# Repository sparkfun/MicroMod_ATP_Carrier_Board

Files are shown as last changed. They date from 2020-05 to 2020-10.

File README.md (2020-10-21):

SparkFun MicroMod ATP Carrier Board
========================================

SparkFun MicroMod ATP Carrier Board (DEV-16885) (https://www.sparkfun.com/products/16885)

[*SparkFun MicroMod ATP Carrier Board (DEV-16885)*](https://www.sparkfun.com/products/16885)

<Basic description of the part.>

Repository Contents
-------------------

* **/Documentation** - Data sheets, additional product information
* **/Firmware** - Example code 
* **/Hardware** - Eagle design files (.brd, .sch)
* **/Production** - Production panel files (.brd)

Documentation
--------------
* **[Hookup Guide](https://learn.sparkfun.com/tutorials/micromod-all-the-pins-atp-carrier-board)** - Basic hookup guide

Product Versions
----------------
* [DEV-16885](https://www.sparkfun.com/products/16885)

Version History
---------------
* [v1.1](https://github.com/sparkfun/MicroMod_ATP_Carrier_Board/tree/v1.1) - Initial Release 

License Information
-------------------

This product is _**open source**_! 

Please review the LICENSE.md file for license information. 

If you have any questions or concerns on licensing, please contact technical support on our [SparkFun forums](https://forum.sparkfun.com/viewforum.php?f=152).

Distributed as-is; no warranty is given.

- Your friends at SparkFun.

_<COLLABORATION CREDIT>_

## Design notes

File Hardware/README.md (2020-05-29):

SparkFun <PRODUCT NAME> Design Files
=====================================

The .sch and .brd files hare are Eagle CAD schematic and PCB design files from SparkFun Electronics.
A freeware version of Eagle can be found [here](http://www.cadsoftusa.com/download-eagle/freeware/).

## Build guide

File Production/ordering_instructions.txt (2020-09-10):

panel size, 195x120mm
PCB thickness, 1.6mm
number of layers, 2
soldermask color, Red
silkscreen color, White
oz copper, 1oz
finish, HASL lead free
stencils, top
pcs per panel, 4
min trace width, 0.1524mm / 0.0060in
min drill size, 0.3048mm / 0.0120in

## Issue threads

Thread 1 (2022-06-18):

I2S_WS or I2S_FS on MicroMod ATP Carrier Board

dboddie, 2022-06-18:
### Subject of the issue
I2S_WS label in the schematic is not present on the board. Either the marking on the board is incorrect or the schematic is wrong.

### Your workbench
* What version of hardware or breakout board are you using?
MicroMod ATP Carrier Board

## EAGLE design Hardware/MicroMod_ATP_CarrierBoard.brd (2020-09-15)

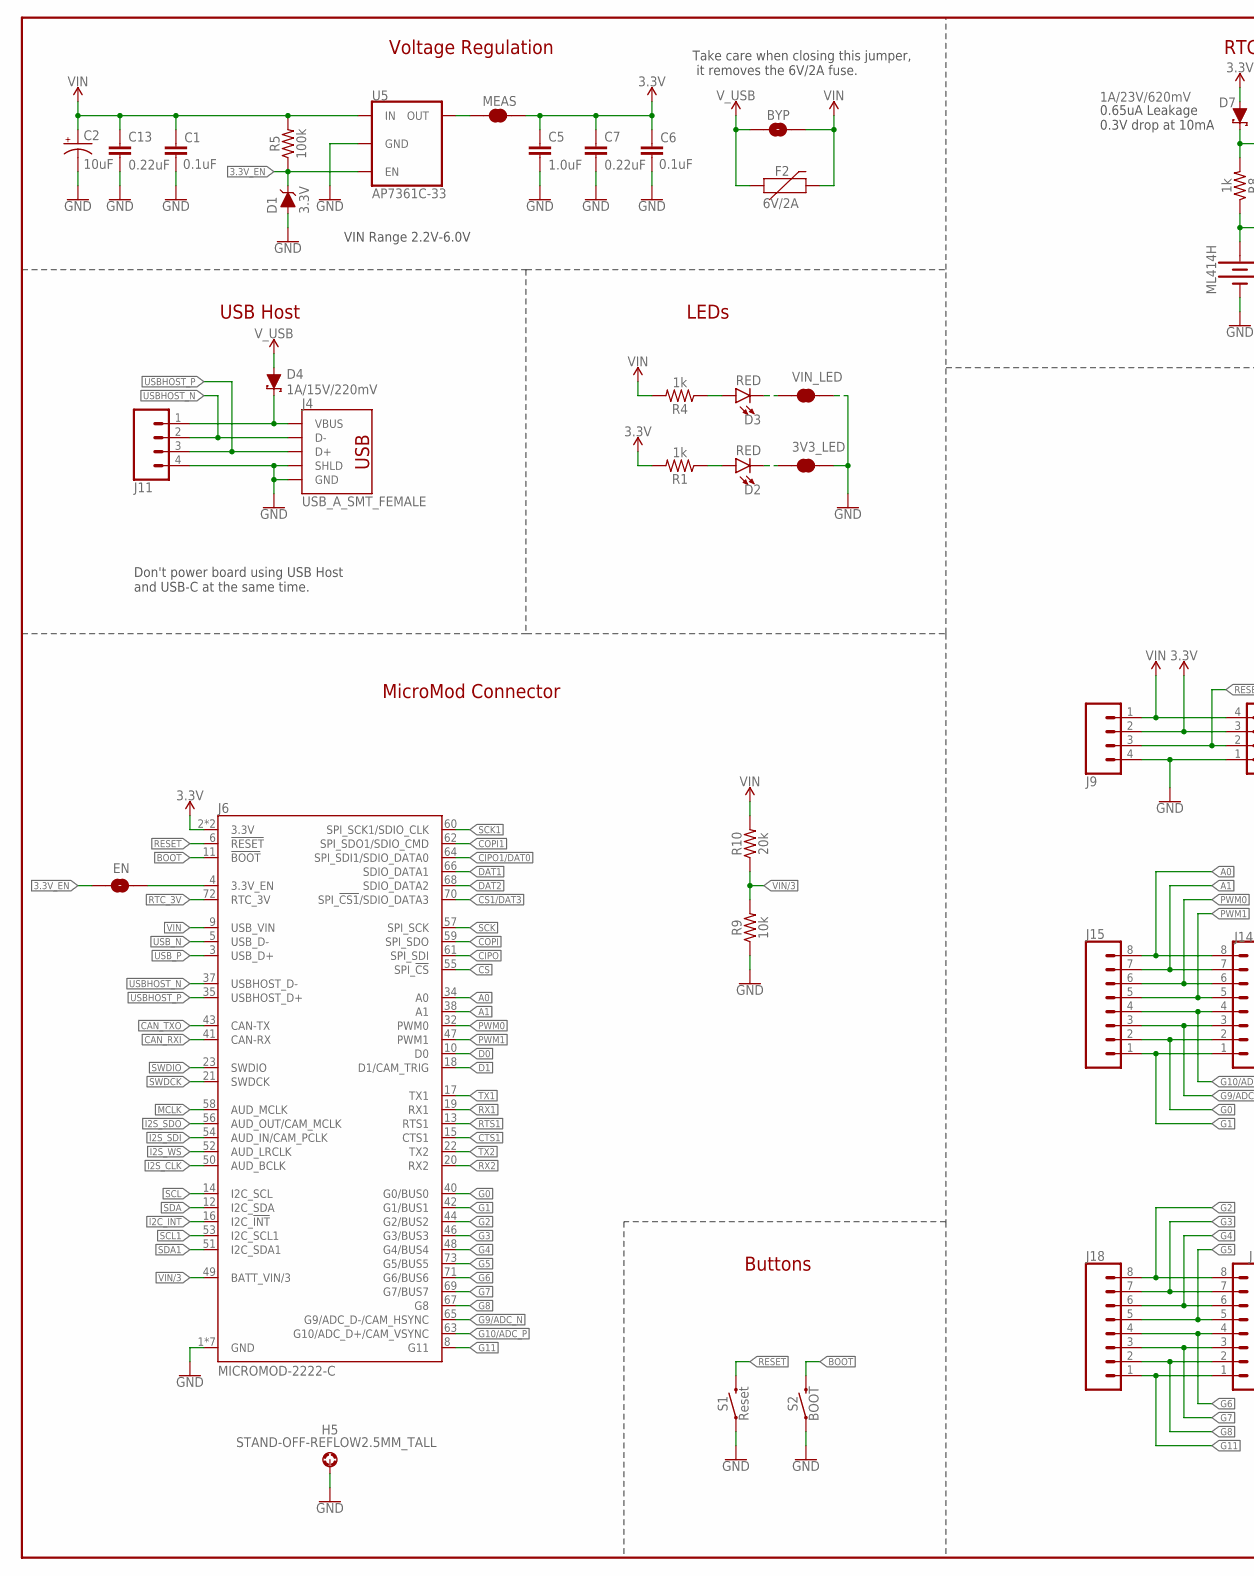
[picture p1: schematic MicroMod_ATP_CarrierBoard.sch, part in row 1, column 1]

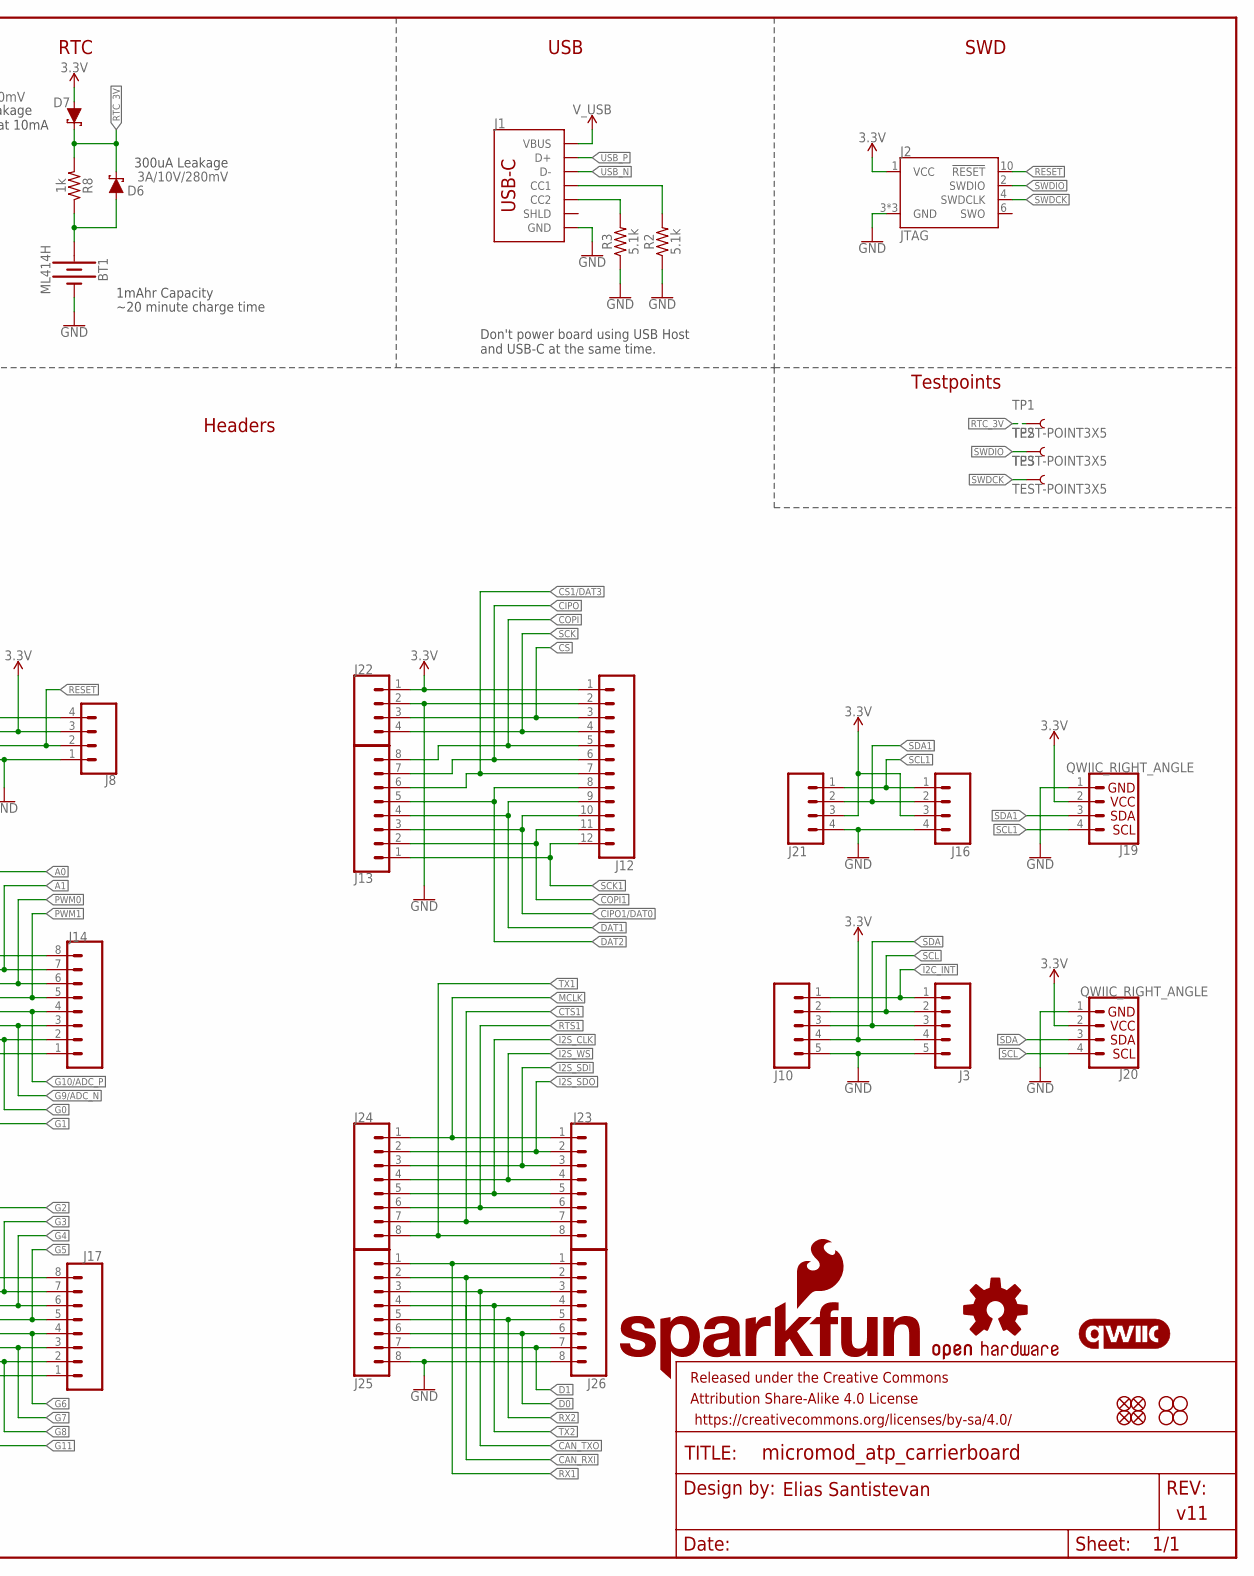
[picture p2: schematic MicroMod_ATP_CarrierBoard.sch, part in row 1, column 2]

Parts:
3V3_LED: JUMPER-SMT_2_NC_TRACE_SILK; SMT-JUMPER_2_NC_TRACE_SILK
BT1: ML414H; ML414H_IV01E
BYP: JUMPER-SMT_2_NO_SILK; SMT-JUMPER_2_NO_SILK
C1, C6: 0.1uF; 0603
C2: 10uF; EIA3216
C5: 1.0uF; 0603
C7, C13: 0.22uF; 0603
D1: 3.3V; SOD-323
D2, D3: RED; LED-0603
D4: 1A/15V/220mV; DO-214BA
D6: 3A/10V/280mV; SOD-323
D7: 1A/23V/620mV; SOD-323
EN: JUMPER-SMT_2_NO_SILK; SMT-JUMPER_2_NO_SILK
F2: 6V/2A; 1210
FD1, FD2, FD3, FD4: FIDUCIALUFIDUCIAL; FIDUCIAL-MICRO
FRAME1: FRAME-LEDGER; CREATIVE_COMMONS
H1, H2, H3, H4: STAND-OFF
H5: STAND-OFF-REFLOW2.5MM_TALL; STAND-OFF-REFLOW-M2.5
J1: USB_C_2-LAYER_PADS; USB-C-16P-2LAYER-PADS
J2: JTAG; 2X5-PTH-1.27MM
J3: CONN_05NO_SILK; 1X05_NO_SILK
J4: USB_A_SMT_FEMALE; USB-A-S-SILK-FEMALE
J6: MICROMOD-2222-C; M.2-CONNECTOR-E
J8, J21: 1X04_SMD_STRAIGHT_COMBO; 1X04_SMD_VERTICAL_COMBO
J9: CONN_041X04_NO_SILK; 1X04_NO_SILK
J10: CONN_05VERT_FEMALE_HEADER; 1X05_SMD_VERTICAL_COMBO
J11, J16, J22: CONN_041X04_NO_SILK_NO_POP; 1X04_NO_SILK
J12: CONN_12SMD_COMBINED; 1X12_SMD_COMBINED
J13: CONN_08NO_SILK_DNP; 1X08_NO_SILK
J14, J17, J24, J25: CONN_08SMD-COMBO-FEMALE; 1X08_SMD_COMBINED
J15, J18, J23, J26: CONN_08NO_SILK_FEMALE_PTH; 1X08_NO_SILK
J19, J20: QWIIC_RIGHT_ANGLE; JST04_1MM_RA
LOGO1: SFE_LOGO_NAME_FLAME.1_INCH; SFE_LOGO_NAME_FLAME_.1
LOGO2: QWIIC_LOGO_5MM; QWIIC_5MM
LOGO3: OSHW-LOGOMINI; OSHW-LOGO-MINI
MEAS: JUMPER-COMBO_2_NC_TRACE; COMBO-JUMPER_2_NC_TRACE
R1, R4, R8: 1k; 0603
R2, R3: 5.1k; 0603
R5: 100k; 0603
R9: 10k; 0603
R10: 20k; 0603
S1: Reset; TACTILE_SWITCH_SMD_5.2MM
S2: BOOT; TACTILE_SWITCH_SMD_5.2MM
TP1, TP2, TP3: TEST-POINT3X5; PAD.03X.05
U5: AP7361C-33; UDFN-8
VIN_LED: JUMPER-SMT_2_NC_TRACE_SILK; SMT-JUMPER_2_NC_TRACE_SILK

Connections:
3.3V: C5.1, C6.1, C7.1, D7.A, J2.1 (VCC), J3.4, J6.2 (3.3V), J6.74 (3.3V), J8.3, J9.2, J10.4, J12.1, J16.3, J19.2, J20.2, J21.3, J22.1, MEAS.2, MEAS.4 (2), R1.2
3.3V_EN: D1.C, EN.1, R5.1, U5.5 (EN)
!BOOT!: J6.11 (!BOOT!), S2.3 (2), S2.4 (2)
!CS1!/DAT3: J6.70 (SPI_!CS1!/SDIO_DATA3), J12.7, J13.6
!CS!: J6.55 (SPI_!CS!), J12.3, J22.3
!RESET: J2.10 (!RESET), J6.6 (!RESET!), J8.2, J9.3, S1.3 (2), S1.4 (2)
A0: J6.34 (A0), J14.8, J15.8
A1: J6.38 (A1), J14.7, J15.7
CAN_RXI: J6.41 (CAN-RX), J25.2, J26.2
CAN_TXO: J6.43 (CAN-TX), J25.3, J26.3
CIPO: J6.61 (SPI_SDI), J12.6, J13.7
CIPO1/DAT0: J6.64 (SPI_SDI1/SDIO_DATA0), J12.10, J13.3
COPI: J6.59 (SPI_SDO), J12.5, J13.8
COPI1: J6.62 (SPI_SDO1/SDIO_CMD), J12.11, J13.2
CTS1: J6.15 (CTS1), J23.7, J24.7
D0: J6.10 (D0), J25.6, J26.6
D1: J6.18 (D1/CAM_TRIG), J25.7, J26.7
DAT1: J6.66 (SDIO_DATA1), J12.9, J13.4
DAT2: J6.68 (SDIO_DATA2), J12.8, J13.5
G0: J6.40 (G0/BUS0), J14.2, J15.2
G1: J6.42 (G1/BUS1), J14.1, J15.1
G2: J6.44 (G2/BUS2), J17.8, J18.8
G3: J6.46 (G3/BUS3), J17.7, J18.7
G4: J6.48 (G4/BUS4), J17.6, J18.6
G5: J6.73 (G5/BUS5), J17.5, J18.5
G6: J6.71 (G6/BUS6), J17.4, J18.4
G7: J6.69 (G7/BUS7), J17.3, J18.3
G8: J6.67 (G8), J17.2, J18.2
G9/ADC_N: J6.65 (G9/ADC_D-/CAM_HSYNC), J14.3, J15.3
G10/ADC_P: J6.63 (G10/ADC_D+/CAM_VSYNC), J14.4, J15.4
G11: J6.8 (G11), J17.1, J18.1
GND: 3V3_LED.2, BT1.-, C1.2, C2.-, C5.2, C6.2, C7.2, C13.2, D1.A, H5.1, J1.GND, J1.GND2 (GND), J2.3 (GND), J2.5 (GND), J2.9 (GND), J3.5, J4.GND, J4.SHLD1 (SHLD), J4.SHLD2 (SHLD), J6.1 (GND), J6.7 (GND), J6.33 (GND), J6.36 (GND), J6.39 (GND), J6.45 (GND), J6.75 (GND), J8.1, J9.4, J10.5, J11.4, J12.2, J16.4, J19.1, J20.1, J21.4, J22.2, J25.8, J26.8, R2.1, R3.1, R9.1, S1.1, S1.2 (1), S2.1, S2.2 (1), U5.4 (GND), U5.EP (GND), VIN_LED.2
I2C_!INT: J3.1, J6.16 (I2C_!INT!), J10.1
I2S_CLK: J6.50 (AUD_BCLK), J23.5, J24.5
I2S_SDI: J6.54 (AUD_IN/CAM_PCLK), J23.3, J24.3
I2S_SDO: J6.56 (AUD_OUT/CAM_MCLK), J23.2, J24.2
I2S_WS: J6.52 (AUD_LRCLK), J23.4, J24.4
MCLK: J6.58 (AUD_MCLK), J23.1, J24.1
unnamed: D2.A, R1.1
unnamed: D3.A, R4.1
unnamed: 3V3_LED.1, D2.C
unnamed: D3.C, VIN_LED.1
unnamed: EN.2, J6.4 (3.3V_EN)
unnamed: D4.C, J4.VBUS, J11.1
unnamed: J1.A5 (CC1), R2.2
unnamed: J1.B5 (CC2), R3.2
unnamed: BT1.+, D6.A, R8.1
OUT_MEAS: MEAS.1, MEAS.3 (1), U5.1 (OUT)
PWM0: J6.32 (PWM0), J14.6, J15.6
PWM1: J6.47 (PWM1), J14.5, J15.5
RTC_3V: D6.C, D7.C, J6.72 (RTC_3V), R8.2, TP1.P$1
RTS1: J6.13 (RTS1), J23.6, J24.6
RX1: J6.19 (RX1), J25.1, J26.1
RX2: J6.20 (RX2), J25.5, J26.5
SCK: J6.57 (SPI_SCK), J12.4, J22.4
SCK1: J6.60 (SPI_SCK1/SDIO_CLK), J12.12, J13.1
SCL: J3.2, J6.14 (I2C_SCL), J10.2, J20.4
SCL1: J6.53 (I2C_SCL1), J16.1, J19.4, J21.1
SDA: J3.3, J6.12 (I2C_SDA), J10.3, J20.3
SDA1: J6.51 (I2C_SDA1), J16.2, J19.3, J21.2
SWDCK: J2.4 (SWDCLK), J6.21 (SWDCK), TP3.P$1
SWDIO: J2.2 (SWDIO), J6.23 (SWDIO), TP2.P$1
TX1: J6.17 (TX1), J23.8, J24.8
TX2: J6.22 (TX2), J25.4, J26.4
USBHOST_N: J4.D-, J6.37 (USBHOST_D-), J11.2
USBHOST_P: J4.D+, J6.35 (USBHOST_D+), J11.3
USB_N: J1.A7 (D-), J1.B7 (D-), J6.5 (USB_D-)
USB_P: J1.A6 (D+), J1.B6 (D+), J6.3 (USB_D+)
VIN: BYP.2, C1.1, C2.+, C13.1, F2.2, J6.9 (USB_VIN), J8.4, J9.1, R4.2, R5.2, R10.2, U5.8 (IN)
VIN/3: J6.49 (BATT_VIN/3), R9.2, R10.1
V_USB: BYP.1, D4.A, F2.1, J1.VBUS1 (VBUS), J1.VBUS2 (VBUS)

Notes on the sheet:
300uA Leakage
0.65uA Leakage 0.3V drop at 10mA
~20 minute charge time
1mAhr Capacity
Take care when closing this jumper, it removes the 6V/2A fuse.
SWD
USB
Headers
RTC
Voltage Regulation
MicroMod Connector
Elias Santistevan
LEDs
USB Host
Buttons
v11
VIN Range 2.2V-6.0V
Don't power board using USB Host and USB-C at the same time.
Testpoints

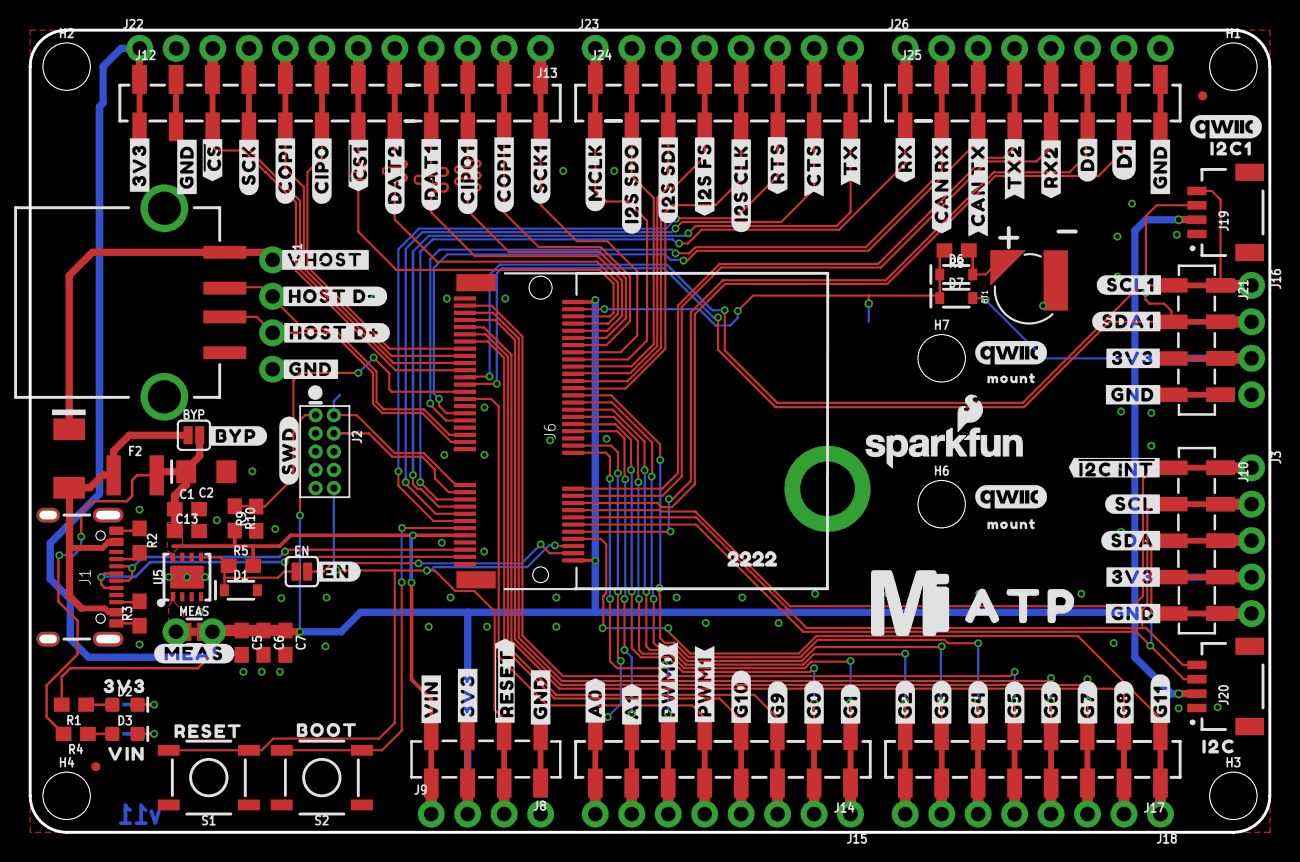
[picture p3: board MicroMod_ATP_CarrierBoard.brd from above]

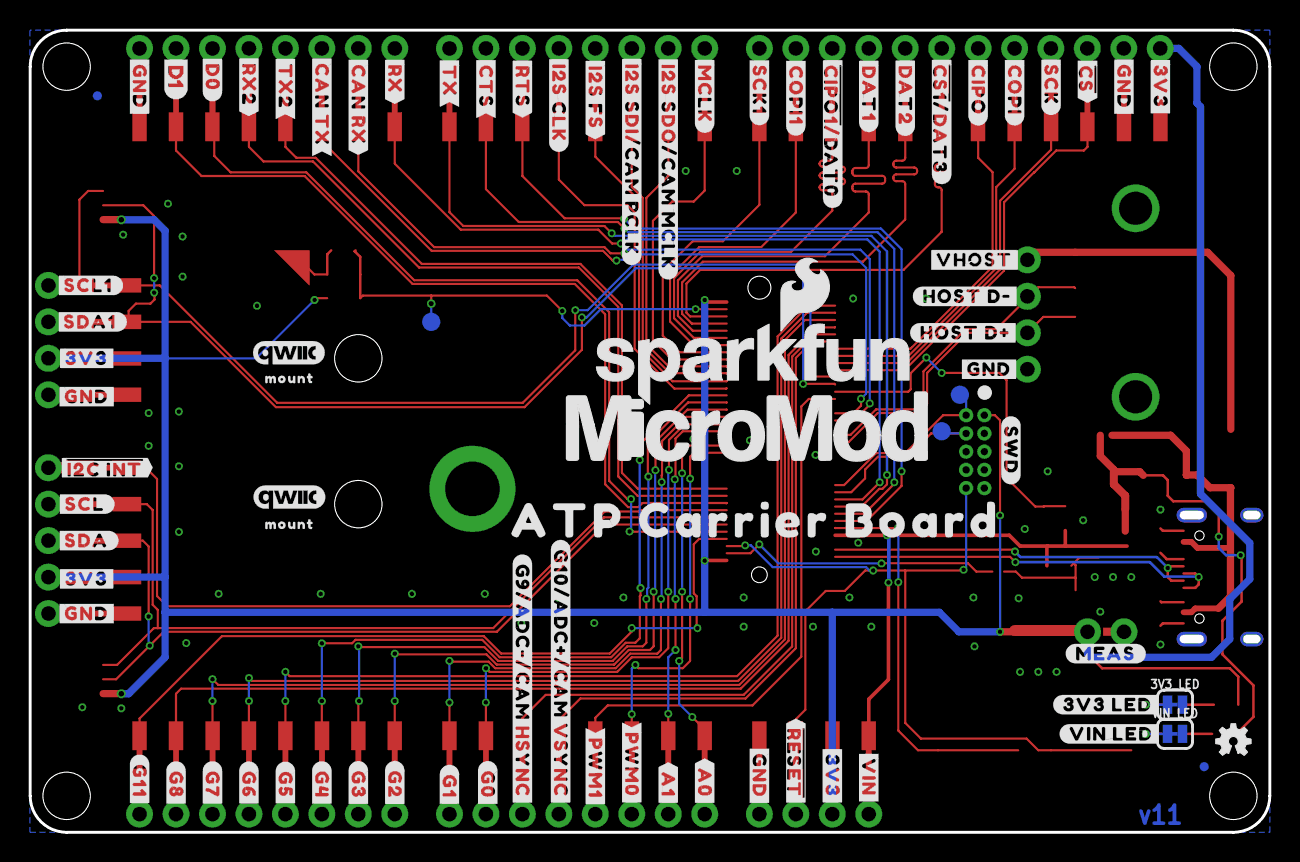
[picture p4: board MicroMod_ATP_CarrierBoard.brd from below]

Board: 2 copper layers, 86.4 x 55.9 mm, 222 parts (80 on the bottom side), 71 nets.

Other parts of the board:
H6, H7: STAND-OFF
LOGO4: SFE_LOGO_NAME_FLAME.2_INCH; SFE_LOGO_NAME_FLAME_.2
LOGO5, LOGO6, LOGO7, LOGO8: QWIIC_LOGO_3MM; QWIIC_5MM
U$1, U$123: #A0#10
U$2, U$124: #A1#10
U$3, U$27, U$46, U$47, U$58, U$89, U$100, U$101, U$102, U$103, U$104, U$105: #GND#0
U$4, U$120: #G0#2
U$5: #RESET10
U$6, U$98: #D0#0
U$7, U$119: #G1#2
U$8, U$118: #G2#2
U$9, U$117: #G3#3
U$10, U$116: #G4#4
U$11, U$115: #G5#5
U$12, U$114: #G6#6
U$13, U$113: #G7#7
U$14, U$112: #G8#8
U$15: #G9#9
U$16: #G10#10
U$17, U$111: #G11#10
U$18, U$121: #PWM0#10
U$19, U$122: #PWM1#10
U$20: ##CS1##5178039
U$21, U$110: ##I2C_INT##10
U$22: #CAN_RX#9
U$23, U$97: #CAN_TX#10
U$24: #CIPO#3
U$25: #COPI#2
U$26: #CTS#6
U$28: #SCK#2
U$29: #I2S_FS#5
U$30: #I2S_SDI#5
U$31: #I2S_SDO#5
U$32: #MCLK#4
U$33: #RTS#5
U$34: #RX#8
U$35: #TX#7
U$36: #DAT1#5178039
U$37, U$125: ##RESET##7
U$38, U$60, U$61, U$70, U$88, U$106, U$107, U$126: #3V3#1
U$39: #BYP#8
U$40, U$128: #HOST_D##9
U$41, U$129: #HOST_D##10
U$42, U$132: #MEAS#10
U$43: BOOT10
U$44, U$108: #SDA#4
U$45, U$127: #VIN#6
U$48: #EN#0
U$49, U$109: #SCL#5
U$50, U$146: #VHOST#0
U$51, U$131: #SWD#10
U$52: #I2S_CLK#5
U$53: #DAT2#5178039
U$54: #CIPO1#5178039
U$55: 22229
U$56: ##CIPO1##DAT0#5178038
U$57, U$75: #COPI1#2
U$59: ##CS##0
U$62: ATP0
U$63, U$76: #RX2#3
U$64, U$80: #TX2#2
U$65, U$78: #SCL1#3
U$66, U$79: #SDA1#3
U$67, U$77: #SCK1#2
U$68: VIN3
U$69: 3V34
U$71: I2C4
U$72: I2C14
U$73: ATP_CARRIER_BOARD1
U$81: ##CS##5178037
U$82: #DAT2#5
U$83: #DAT1#5
U$84: ##CS1##DAT3#5178037
U$85: #COPI#4
U$86: #SCK#4
U$87: #MCLK#6
U$90: #I2S_FS#7
U$91: #I2S_CLK#7
U$92: #RTS#7
U$93: #CTS#8
U$94: #TX#9
U$95: #RX#10
U$96: #CAN_RX#10
U$99, U$145: D10
U$133: #VIN_LED#10
U$134: #3V3_LED#10
U$135: #G9#ADC##CAM_HSYNC#9
U$136: #G10#ADC##CAM_VSYNC#10
U$137: #I2S_SDI#CAM_PCLK#7
U$138: #I2S_SDO#CAM_MCLK#7
U$139, U$141, U$142, U$143: MOUNT10
U$140: MICROMOD_MI_LOGO_1
U$144: MICROMOD_LOGO_1
U$147: #CIPO#5178038

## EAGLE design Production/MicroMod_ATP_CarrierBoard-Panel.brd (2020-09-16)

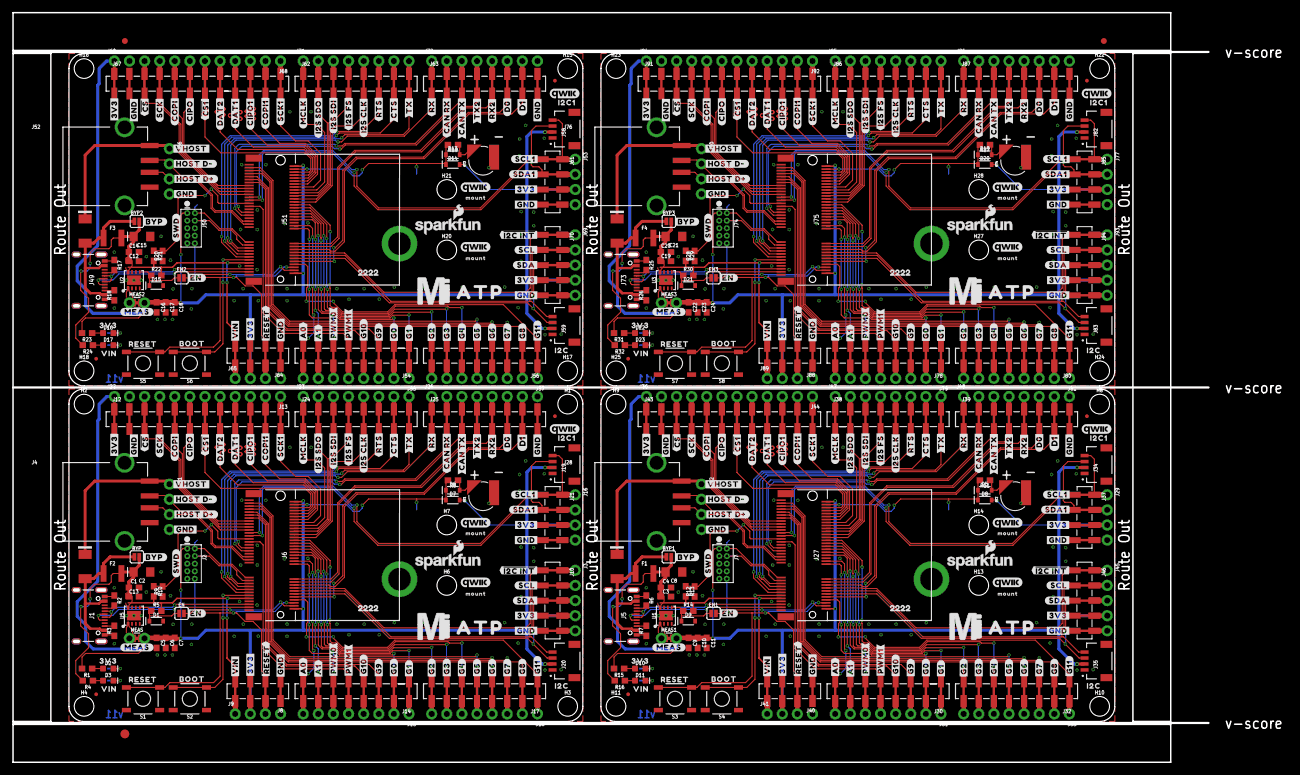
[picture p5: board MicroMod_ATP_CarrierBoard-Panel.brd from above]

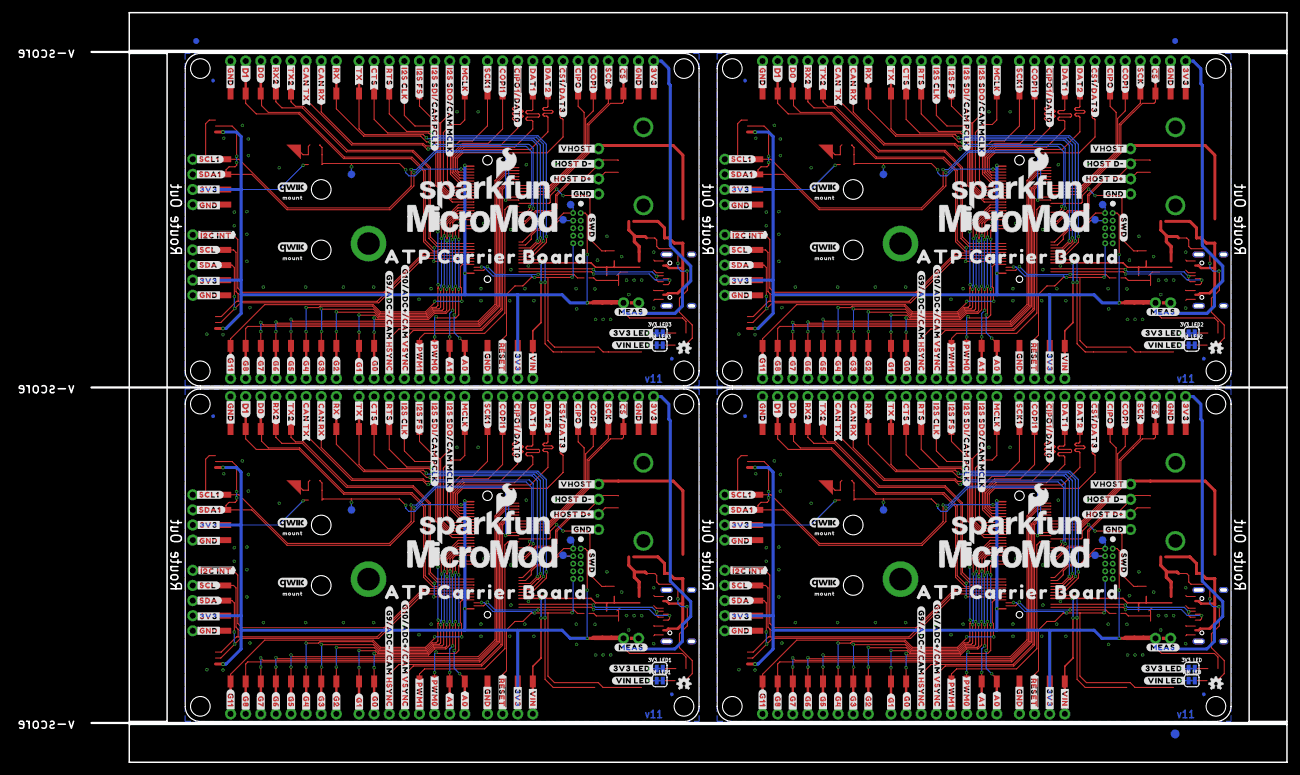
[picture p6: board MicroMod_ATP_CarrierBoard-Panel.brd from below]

Board: 2 copper layers, 200.9 x 126.0 mm, 890 parts (323 on the bottom side), 284 nets.

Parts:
3V3_LED, 3V3_LED1, 3V3_LED2, 3V3_LED3: JUMPER-SMT_2_NC_TRACE_SILK; SMT-JUMPER_2_NC_TRACE_SILK
BT1, BT2, BT3, BT4: ML414H; ML414H_IV01E
BYP, BYP1, BYP2, BYP3: JUMPER-SMT_2_NO_SILK; SMT-JUMPER_2_NO_SILK
C1, C4, C6, C10, C14, C17, C20, C23: 0.1uF; 0603
C2, C8, C15, C21: 10uF; EIA3216
C3, C7, C11, C12, C13, C18, C19, C24: 0.22uF; 0603
C5, C9, C16, C22: 1.0uF; 0603
D1, D9, D15, D21: 3.3V; SOD-323
D2, D3, D10, D11, D16, D17, D22, D23: RED; LED-0603
D4, D12, D18, D24: 1A/15V/220mV; DO-214BA
D5, D6, D13, D19: 3A/10V/280mV; SOD-323
D7, D8, D14, D20: 1A/23V/620mV; SOD-323
E$1, E$2, E$3, E$4: FIDUCIAL-1X2
E$5, E$6: FIDUCIAL-1.5X3
EN, EN1, EN2, EN3: JUMPER-SMT_2_NO_SILK; SMT-JUMPER_2_NO_SILK
F1, F2, F3, F4: 6V/2A; 1210
FD1, FD2, FD3, FD4, FD5, FD6, FD7, FD8, FD9, FD10, FD11, FD12, FD13, FD14, FD15, FD16: FIDUCIALUFIDUCIAL; FIDUCIAL-MICRO
H1, H2, H3, H4, H6, H7, H8, H9, H10, H11, H13, H14, H15, H16, H17, H18, H20, H21, H22, H23, H24, H25, H27, H28: STAND-OFF
H5, H12, H19, H26: STAND-OFF-REFLOW2.5MM_TALL; STAND-OFF-REFLOW-M2.5
J1, J5, J49, J73: USB-C-16P-2LAYER-PADS
J2, J7, J50, J74: JTAG; 2X5-PTH-1.27MM
J3, J45, J69, J93: 1X05_NO_SILK
J4, J28, J52, J76: USB_A_SMT_FEMALE; USB-A-S-SILK-FEMALE
J6, J27, J51, J75: MICROMOD-2222-C; M.2-CONNECTOR-E
J8, J21, J37, J40, J61, J64, J85, J88: 1X04_SMD_STRAIGHT_COMBO; 1X04_SMD_VERTICAL_COMBO
J9, J11, J16, J22, J29, J36, J41, J42, J53, J60, J65, J66, J77, J84, J89, J90: 1X04_NO_SILK
J10, J46, J70, J94: 1X05_SMD_VERTICAL_COMBO
J12, J43, J67, J91: 1X12_SMD_COMBINED
J13, J15, J18, J23, J26, J31, J33, J44, J47, J48, J55, J57, J68, J71, J72, J79, J81, J92, J95, J96: 1X08_NO_SILK
J14, J17, J24, J25, J30, J32, J38, J39, J54, J56, J62, J63, J78, J80, J86, J87: 1X08_SMD_COMBINED
J19, J20, J34, J35, J58, J59, J82, J83: QWIIC_RIGHT_ANGLE; JST04_1MM_RA
LOGO1, LOGO11, LOGO19, LOGO27: SFE_LOGO_NAME_FLAME.1_INCH; SFE_LOGO_NAME_FLAME_.1
LOGO2, LOGO15, LOGO23, LOGO31: QWIIC_LOGO_5MM; QWIIC_5MM
LOGO3, LOGO9, LOGO17, LOGO25: OSHW-LOGOMINI; OSHW-LOGO-MINI
LOGO4, LOGO10, LOGO18, LOGO26: SFE_LOGO_NAME_FLAME.2_INCH; SFE_LOGO_NAME_FLAME_.2
LOGO5, LOGO6, LOGO7, LOGO8, LOGO12, LOGO13, LOGO14, LOGO16, LOGO20, LOGO21, LOGO22, LOGO24, LOGO28, LOGO29, LOGO30, LOGO32: QWIIC_LOGO_3MM; QWIIC_5MM
MEAS, MEAS1, MEAS2, MEAS3: COMBO-JUMPER_2_NC_TRACE
R1, R4, R8, R11, R15, R16, R19, R23, R24, R27, R31, R32: 1k; 0603
R2, R3, R6, R7, R17, R18, R25, R26: 5.1k; 0603
R5, R14, R22, R30: 100k; 0603
R9, R12, R20, R28: 10k; 0603
R10, R13, R21, R29: 20k; 0603
S1, S3, S5, S7: Reset; TACTILE_SWITCH_SMD_5.2MM
S2, S4, S6, S8: BOOT; TACTILE_SWITCH_SMD_5.2MM
TP1, TP2, TP3, TP4, TP5, TP6, TP7, TP8, TP9, TP10, TP11, TP12: TEST-POINT3X5; PAD.03X.05
U1, U2, U3, U5: AP7361C-33; UDFN-8
U$1, U$123, U$169, U$251, U$314, U$396, U$459, U$541: #A0#10
U$2, U$124, U$170, U$252, U$315, U$397, U$460, U$542: #A1#10
U$3, U$27, U$46, U$47, U$58, U$89, U$100, U$101, U$102, U$103, U$104, U$105, U$160, U$166, U$167, U$228, U$229, U$230, U$231, U$232, U$233, U$268, U$269, U$270, U$305, U$311, U$312, U$373, U$374, U$375, U$376, U$377, U$378, U$413, U$414, U$415, U$450, U$456, U$457, U$518, U$519, U$520, U$521, U$522, U$523, U$558, U$559, U$560: #GND#0
U$4, U$120, U$172, U$248, U$317, U$393, U$462, U$538: #G0#2
U$5, U$163, U$308, U$453: #RESET10
U$6, U$98, U$171, U$227, U$316, U$372, U$461, U$517: #D0#0
U$7, U$119, U$173, U$247, U$318, U$392, U$463, U$537: #G1#2
U$8, U$118, U$174, U$246, U$319, U$391, U$464, U$536: #G2#2
U$9, U$117, U$175, U$245, U$320, U$390, U$465, U$535: #G3#3
U$10, U$116, U$176, U$244, U$321, U$389, U$466, U$534: #G4#4
U$11, U$115, U$177, U$243, U$322, U$388, U$467, U$533: #G5#5
U$12, U$114, U$178, U$242, U$323, U$387, U$468, U$532: #G6#6
U$13, U$113, U$179, U$241, U$324, U$386, U$469, U$531: #G7#7
U$14, U$112, U$180, U$240, U$325, U$385, U$470, U$530: #G8#8
U$15, U$181, U$326, U$471: #G9#9
U$16, U$182, U$327, U$472: #G10#10
U$17, U$111, U$183, U$239, U$328, U$384, U$473, U$529: #G11#10
U$18, U$121, U$184, U$249, U$329, U$394, U$474, U$539: #PWM0#10
U$19, U$122, U$185, U$250, U$330, U$395, U$475, U$540: #PWM1#10
U$20, U$286, U$431, U$576: ##CS1##5178039
U$21, U$110, U$238, U$271, U$383, U$416, U$528, U$561: ##I2C_INT##10
U$22, U$130, U$292, U$437: #CAN_RX#9
U$23, U$97, U$148, U$226, U$293, U$371, U$438, U$516: #CAN_TX#10
U$24, U$149, U$294, U$439: #CIPO#3
U$25, U$150, U$295, U$440: #COPI#2
U$26, U$151, U$296, U$441: #CTS#6
U$28, U$267, U$412, U$557: #SCK#2
U$29, U$152, U$297, U$442: #I2S_FS#5
U$30, U$153, U$298, U$443: #I2S_SDI#5
U$31, U$154, U$299, U$444: #I2S_SDO#5
U$32, U$155, U$300, U$445: #MCLK#4
U$33, U$156, U$301, U$446: #RTS#5
U$34, U$157, U$302, U$447: #RX#8
U$35, U$158, U$303, U$448: #TX#7
U$36, U$287, U$432, U$577: #DAT1#5178039
U$37, U$125, U$206, U$253, U$351, U$398, U$496, U$543: ##RESET##7
U$38, U$60, U$61, U$70, U$88, U$106, U$107, U$126, U$197, U$198, U$199, U$200, U$234, U$235, U$254, U$266, U$342, U$343, U$344, U$345, U$379, U$380, U$399, U$411, U$487, U$488, U$489, U$490, U$524, U$525, U$544, U$556: #3V3#1
U$39, U$159, U$304, U$449: #BYP#8
U$40, U$128, U$161, U$256, U$306, U$401, U$451, U$546: #HOST_D##9
U$41, U$129, U$162, U$257, U$307, U$402, U$452, U$547: #HOST_D##10
U$42, U$132, U$186, U$259, U$331, U$404, U$476, U$549: #MEAS#10
U$43, U$164, U$309, U$454: BOOT10
U$44, U$108, U$187, U$236, U$332, U$381, U$477, U$526: #SDA#4
U$45, U$127, U$165, U$255, U$310, U$400, U$455, U$545: #VIN#6
U$48, U$280, U$425, U$570: #EN#0
U$49, U$109, U$168, U$237, U$313, U$382, U$458, U$527: #SCL#5
U$50, U$146, U$281, U$282, U$426, U$427, U$571, U$572: #VHOST#0
U$51, U$131, U$188, U$258, U$333, U$403, U$478, U$548: #SWD#10
U$52, U$189, U$334, U$479: #I2S_CLK#5
U$53, U$288, U$433, U$578: #DAT2#5178039
U$54, U$289, U$434, U$579: #CIPO1#5178039
U$55, U$74, U$291, U$436: 22229
U$56, U$290, U$435, U$580: ##CIPO1##DAT0#5178038
U$57, U$75, U$205, U$208, U$350, U$353, U$495, U$498: #COPI1#2
U$59, U$207, U$352, U$497: ##CS##0
U$62, U$201, U$346, U$491: ATP0
U$63, U$76, U$190, U$209, U$335, U$354, U$480, U$499: #RX2#3
U$64, U$80, U$191, U$213, U$336, U$358, U$481, U$503: #TX2#2
U$65, U$78, U$192, U$211, U$337, U$356, U$482, U$501: #SCL1#3
U$66, U$79, U$193, U$212, U$338, U$357, U$483, U$502: #SDA1#3
U$67, U$77, U$194, U$210, U$339, U$355, U$484, U$500: #SCK1#2
U$68, U$195, U$340, U$485: VIN3
U$69, U$196, U$341, U$486: 3V34
U$71, U$202, U$347, U$492: I2C4
U$72, U$203, U$348, U$493: I2C14
U$73, U$204, U$349, U$494: ATP_CARRIER_BOARD1
U$81, U$283, U$428, U$573: ##CS##5178037
U$82, U$214, U$359, U$504: #DAT2#5
U$83, U$215, U$360, U$505: #DAT1#5
U$84, U$284, U$429, U$574: ##CS1##DAT3#5178037
U$85, U$216, U$361, U$506: #COPI#4
U$86, U$217, U$362, U$507: #SCK#4
U$87, U$218, U$363, U$508: #MCLK#6
U$90, U$219, U$364, U$509: #I2S_FS#7
U$91, U$220, U$365, U$510: #I2S_CLK#7
U$92, U$221, U$366, U$511: #RTS#7
U$93, U$222, U$367, U$512: #CTS#8
U$94, U$223, U$368, U$513: #TX#9
U$95, U$224, U$369, U$514: #RX#10
U$96, U$225, U$370, U$515: #CAN_RX#10
U$99, U$145, U$272, U$279, U$417, U$424, U$562, U$569: D10
U$133, U$260, U$405, U$550: #VIN_LED#10
U$134, U$261, U$406, U$551: #3V3_LED#10
U$135, U$262, U$407, U$552: #G9#ADC##CAM_HSYNC#9
U$136, U$263, U$408, U$553: #G10#ADC##CAM_VSYNC#10
U$137, U$264, U$409, U$554: #I2S_SDI#CAM_PCLK#7
U$138, U$265, U$410, U$555: #I2S_SDO#CAM_MCLK#7
U$139, U$141, U$142, U$143, U$274, U$275, U$276, U$277, U$419, U$420, U$421, U$422, U$564, U$565, U$566, U$567: MOUNT10
U$140, U$273, U$418, U$563: MICROMOD_MI_LOGO_1
U$144, U$278, U$423, U$568: MICROMOD_LOGO_1
U$147, U$285, U$430, U$575: #CIPO#5178038
VIN_LED, VIN_LED1, VIN_LED2, VIN_LED3: JUMPER-SMT_2_NC_TRACE_SILK; SMT-JUMPER_2_NC_TRACE_SILK

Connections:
3.3V: C5.1, C6.1, C7.1, D7.A, J2.1, J3.4, J6.2, J6.74, J8.3, J9.2, J10.4, J12.1, J16.3, J19.2, J20.2, J21.3, J22.1, MEAS.2, MEAS.4, R1.2
3.3V1: C9.1, C10.1, C11.1, D8.A, J7.1, J27.2, J27.74, J29.3, J34.2, J35.2, J36.1, J37.3, J40.3, J41.2, J43.1, J45.4, J46.4, MEAS1.2, MEAS1.4, R15.2
3.3V2: C16.1, C17.1, C18.1, D14.A, J50.1, J51.2, J51.74, J53.3, J58.2, J59.2, J60.1, J61.3, J64.3, J65.2, J67.1, J69.4, J70.4, MEAS2.2, MEAS2.4, R23.2
3.3V3: C22.1, C23.1, C24.1, D20.A, J74.1, J75.2, J75.74, J77.3, J82.2, J83.2, J84.1, J85.3, J88.3, J89.2, J91.1, J93.4, J94.4, MEAS3.2, MEAS3.4, R31.2
3.3V_EN: D1.C, EN.1, R5.1, U5.5
3.3V_EN1: D9.C, EN1.1, R14.1, U1.5
3.3V_EN2: D15.C, EN2.1, R22.1, U2.5
3.3V_EN3: D21.C, EN3.1, R30.1, U3.5
!BOOT!: J6.11, S2.3, S2.4
!BOOT!1: J27.11, S4.3, S4.4
!BOOT!2: J51.11, S6.3, S6.4
!BOOT!3: J75.11, S8.3, S8.4
!CS1!/DAT1: J27.70, J43.7, J44.6
!CS1!/DAT2: J51.70, J67.7, J68.6
!CS1!/DAT3: J6.70, J12.7, J13.6
!CS1!/DAT4: J75.70, J91.7, J92.6
!CS!: J6.55, J12.3, J22.3
!CS!1: J27.55, J36.3, J43.3
!CS!2: J51.55, J60.3, J67.3
!CS!3: J75.55, J84.3, J91.3
!RESET: J2.10, J6.6, J8.2, J9.3, S1.3, S1.4
!RESET1: J7.10, J27.6, J40.2, J41.3, S3.3, S3.4
!RESET2: J50.10, J51.6, J64.2, J65.3, S5.3, S5.4
!RESET3: J74.10, J75.6, J88.2, J89.3, S7.3, S7.4
A0: J6.34, J14.8, J15.8
A1: J6.38, J14.7, J15.7
A2: J27.34, J30.8, J31.8
A3: J27.38, J30.7, J31.7
A4: J51.34, J54.8, J55.8
A5: J51.38, J54.7, J55.7
A6: J75.34, J78.8, J79.8
A7: J75.38, J78.7, J79.7
CAN_RXI: J6.41, J25.2, J26.2
CAN_RXI1: J27.41, J39.2, J48.2
CAN_RXI2: J51.41, J63.2, J72.2
CAN_RXI3: J75.41, J87.2, J96.2
CAN_TXO: J6.43, J25.3, J26.3
CAN_TXO1: J27.43, J39.3, J48.3
CAN_TXO2: J51.43, J63.3, J72.3
CAN_TXO3: J75.43, J87.3, J96.3
CIPO: J6.61, J12.6, J13.7
CIPO1: J27.61, J43.6, J44.7
CIPO1/DAT0: J6.64, J12.10, J13.3
CIPO1/DAT1: J27.64, J43.10, J44.3
CIPO1/DAT2: J51.64, J67.10, J68.3
CIPO1/DAT3: J75.64, J91.10, J92.3
CIPO2: J51.61, J67.6, J68.7
CIPO3: J75.61, J91.6, J92.7
COPI: J6.59, J12.5, J13.8
COPI1: J6.62, J12.11, J13.2
COPI2: J27.59, J43.5, J44.8
COPI3: J27.62, J43.11, J44.2
COPI4: J51.59, J67.5, J68.8
COPI5: J51.62, J67.11, J68.2
COPI6: J75.59, J91.5, J92.8
COPI7: J75.62, J91.11, J92.2
CTS1: J6.15, J23.7, J24.7
CTS2: J27.15, J38.7, J47.7
CTS3: J51.15, J62.7, J71.7
CTS4: J75.15, J86.7, J95.7
D0: J6.10, J25.6, J26.6
D1: J6.18, J25.7, J26.7
D2: J27.10, J39.6, J48.6
D3: J27.18, J39.7, J48.7
D4: J51.10, J63.6, J72.6
D5: J51.18, J63.7, J72.7
D6: J75.10, J87.6, J96.6
D7: J75.18, J87.7, J96.7
DAT1: J6.66, J12.9, J13.4
DAT2: J6.68, J12.8, J13.5
DAT3: J27.66, J43.9, J44.4
DAT4: J27.68, J43.8, J44.5
DAT5: J51.66, J67.9, J68.4
DAT6: J51.68, J67.8, J68.5
DAT7: J75.66, J91.9, J92.4
DAT8: J75.68, J91.8, J92.5
G0: J6.40, J14.2, J15.2
G1: J6.42, J14.1, J15.1
G2: J6.44, J17.8, J18.8
G3: J6.46, J17.7, J18.7
G4: J6.48, J17.6, J18.6
G5: J6.73, J17.5, J18.5
G6: J6.71, J17.4, J18.4
G7: J6.69, J17.3, J18.3
G8: J6.67, J17.2, J18.2
G9: J27.40, J30.2, J31.2
G9/ADC_N: J6.65, J14.3, J15.3
G9/ADC_N1: J27.65, J30.3, J31.3
G9/ADC_N2: J51.65, J54.3, J55.3
G9/ADC_N3: J75.65, J78.3, J79.3
G10: J27.42, J30.1, J31.1
G10/ADC_P: J6.63, J14.4, J15.4
G10/ADC_P1: J27.63, J30.4, J31.4
G10/ADC_P2: J51.63, J54.4, J55.4
G10/ADC_P3: J75.63, J78.4, J79.4
G11: J6.8, J17.1, J18.1
G12: J27.73, J32.5, J33.5
G13: J27.48, J32.6, J33.6
G14: J27.44, J32.8, J33.8
G15: J27.69, J32.3, J33.3
G16: J27.46, J32.7, J33.7
G17: J27.71, J32.4, J33.4
G18: J27.67, J32.2, J33.2
G19: J27.8, J32.1, J33.1
G20: J51.40, J54.2, J55.2
G21: J51.42, J54.1, J55.1
G22: J51.73, J56.5, J57.5
G23: J51.48, J56.6, J57.6
G24: J51.44, J56.8, J57.8
G25: J51.69, J56.3, J57.3
G26: J51.46, J56.7, J57.7
G27: J51.71, J56.4, J57.4
G28: J51.67, J56.2, J57.2
G29: J51.8, J56.1, J57.1
G30: J75.40, J78.2, J79.2
G31: J75.42, J78.1, J79.1
G32: J75.73, J80.5, J81.5
G33: J75.48, J80.6, J81.6
G34: J75.44, J80.8, J81.8
G35: J75.69, J80.3, J81.3
G36: J75.46, J80.7, J81.7
G37: J75.71, J80.4, J81.4
G38: J75.67, J80.2, J81.2
G39: J75.8, J80.1, J81.1
GND: 3V3_LED.2, BT1.-, C1.2, C2.-, C5.2, C6.2, C7.2, C13.2, D1.A, H5.1, J1.GND, J1.GND2, J2.3, J2.5, J2.9, J3.5, J4.GND, J4.SHLD1, J4.SHLD2, J6.1, J6.7, J6.33, J6.36, J6.39, J6.45, J6.75, J8.1, J9.4, J10.5, J11.4, J12.2, J16.4, J19.1, J20.1, J21.4, J22.2, J25.8, J26.8, R2.1, R3.1, R9.1, S1.1, S1.2, S2.1, S2.2, U5.4, U5.EP, VIN_LED.2
GND1: 3V3_LED1.2, BT2.-, C3.2, C4.2, C8.-, C9.2, C10.2, C11.2, D9.A, H12.1, J5.GND, J5.GND2, J7.3, J7.5, J7.9, J27.1, J27.7, J27.33, J27.36, J27.39, J27.45, J27.75, J28.GND, J28.SHLD1, J28.SHLD2, J29.4, J34.1, J35.1, J36.2, J37.4, J39.8, J40.1, J41.4, J42.4, J43.2, J45.5, J46.5, J48.8, R6.1, R7.1, R12.1, S3.1, S3.2, S4.1, S4.2, U1.4, U1.EP, VIN_LED1.2
GND2: 3V3_LED2.2, BT3.-, C12.2, C14.2, C15.-, C16.2, C17.2, C18.2, D15.A, H19.1, J49.GND, J49.GND2, J50.3, J50.5, J50.9, J51.1, J51.7, J51.33, J51.36, J51.39, J51.45, J51.75, J52.GND, J52.SHLD1, J52.SHLD2, J53.4, J58.1, J59.1, J60.2, J61.4, J63.8, J64.1, J65.4, J66.4, J67.2, J69.5, J70.5, J72.8, R17.1, R18.1, R20.1, S5.1, S5.2, S6.1, S6.2, U2.4, U2.EP, VIN_LED2.2
GND3: 3V3_LED3.2, BT4.-, C19.2, C20.2, C21.-, C22.2, C23.2, C24.2, D21.A, H26.1, J73.GND, J73.GND2, J74.3, J74.5, J74.9, J75.1, J75.7, J75.33, J75.36, J75.39, J75.45, J75.75, J76.GND, J76.SHLD1, J76.SHLD2, J77.4, J82.1, J83.1, J84.2, J85.4, J87.8, J88.1, J89.4, J90.4, J91.2, J93.5, J94.5, J96.8, R25.1, R26.1, R28.1, S7.1, S7.2, S8.1, S8.2, U3.4, U3.EP, VIN_LED3.2
I2C_!INT: J3.1, J6.16, J10.1
I2C_!INT1: J27.16, J45.1, J46.1
I2C_!INT2: J51.16, J69.1, J70.1
I2C_!INT3: J75.16, J93.1, J94.1
I2S_CLK: J6.50, J23.5, J24.5
I2S_CLK1: J27.50, J38.5, J47.5
I2S_CLK2: J51.50, J62.5, J71.5
I2S_CLK3: J75.50, J86.5, J95.5
I2S_SDI: J6.54, J23.3, J24.3
I2S_SDI1: J27.54, J38.3, J47.3
I2S_SDI2: J51.54, J62.3, J71.3
I2S_SDI3: J75.54, J86.3, J95.3
I2S_SDO: J6.56, J23.2, J24.2
I2S_SDO1: J27.56, J38.2, J47.2
I2S_SDO2: J51.56, J62.2, J71.2
I2S_SDO3: J75.56, J86.2, J95.2
I2S_WS: J6.52, J23.4, J24.4
I2S_WS1: J27.52, J38.4, J47.4
I2S_WS2: J51.52, J62.4, J71.4
I2S_WS3: J75.52, J86.4, J95.4
MCLK: J6.58, J23.1, J24.1
MCLK1: J27.58, J38.1, J47.1
MCLK2: J51.58, J62.1, J71.1
MCLK3: J75.58, J86.1, J95.1
unnamed: D2.A, R1.1
unnamed: D3.A, R4.1
unnamed: 3V3_LED.1, D2.C
unnamed: D3.C, VIN_LED.1
unnamed: EN.2, J6.4
unnamed: J5.A5, R6.2
unnamed: D4.C, J4.VBUS, J11.1
unnamed: J5.B5, R7.2
unnamed: BT2.+, D5.A, R11.1
unnamed: J1.A5, R2.2
unnamed: J1.B5, R3.2
unnamed: D10.A, R15.1
unnamed: D11.A, R16.1
unnamed: BT1.+, D6.A, R8.1
unnamed: 3V3_LED1.1, D10.C
unnamed: D11.C, VIN_LED1.1
unnamed: EN1.2, J27.4
unnamed: D12.C, J28.VBUS, J42.1
unnamed: J49.A5, R17.2
unnamed: J49.B5, R18.2
unnamed: BT3.+, D13.A, R19.1
unnamed: D16.A, R23.1
unnamed: D17.A, R24.1
unnamed: 3V3_LED2.1, D16.C
unnamed: D17.C, VIN_LED2.1
unnamed: EN2.2, J51.4
unnamed: D18.C, J52.VBUS, J66.1
unnamed: J73.A5, R25.2
unnamed: J73.B5, R26.2
unnamed: BT4.+, D19.A, R27.1
unnamed: D22.A, R31.1
unnamed: D23.A, R32.1
unnamed: 3V3_LED3.1, D22.C
unnamed: D23.C, VIN_LED3.1
unnamed: EN3.2, J75.4
unnamed: D24.C, J76.VBUS, J90.1
OUT_MEAS: MEAS.1, MEAS.3, U5.1
OUT_MEAS1: MEAS1.1, MEAS1.3, U1.1
OUT_MEAS2: MEAS2.1, MEAS2.3, U2.1
OUT_MEAS3: MEAS3.1, MEAS3.3, U3.1
PWM0: J6.32, J14.6, J15.6
PWM1: J6.47, J14.5, J15.5
PWM2: J27.32, J30.6, J31.6
PWM3: J27.47, J30.5, J31.5
PWM4: J51.32, J54.6, J55.6
PWM5: J51.47, J54.5, J55.5
PWM6: J75.32, J78.6, J79.6
PWM7: J75.47, J78.5, J79.5
RTC_3V: D6.C, D7.C, J6.72, R8.2, TP1.P$1
RTC_3V1: D5.C, D8.C, J27.72, R11.2, TP4.P$1
RTC_3V2: D13.C, D14.C, J51.72, R19.2, TP7.P$1
RTC_3V3: D19.C, D20.C, J75.72, R27.2, TP10.P$1
RTS1: J6.13, J23.6, J24.6
RTS2: J27.13, J38.6, J47.6
RTS3: J51.13, J62.6, J71.6
RTS4: J75.13, J86.6, J95.6
RX1: J6.19, J25.1, J26.1
RX2: J6.20, J25.5, J26.5
RX3: J27.19, J39.1, J48.1
RX4: J27.20, J39.5, J48.5
RX5: J51.19, J63.1, J72.1
RX6: J51.20, J63.5, J72.5
RX7: J75.19, J87.1, J96.1
RX8: J75.20, J87.5, J96.5
SCK: J6.57, J12.4, J22.4
SCK1: J6.60, J12.12, J13.1
SCK2: J27.57, J36.4, J43.4
SCK3: J27.60, J43.12, J44.1
SCK4: J51.57, J60.4, J67.4
SCK5: J51.60, J67.12, J68.1
SCK6: J75.57, J84.4, J91.4
SCK7: J75.60, J91.12, J92.1
SCL: J3.2, J6.14, J10.2, J20.4
SCL1: J6.53, J16.1, J19.4, J21.1
SCL2: J27.14, J35.4, J45.2, J46.2
SCL3: J27.53, J29.1, J34.4, J37.1
SCL4: J51.14, J59.4, J69.2, J70.2
SCL5: J51.53, J53.1, J58.4, J61.1
SCL6: J75.14, J83.4, J93.2, J94.2
SCL7: J75.53, J77.1, J82.4, J85.1
SDA: J3.3, J6.12, J10.3, J20.3
SDA1: J6.51, J16.2, J19.3, J21.2
SDA2: J27.12, J35.3, J45.3, J46.3
SDA3: J27.51, J29.2, J34.3, J37.2
SDA4: J51.12, J59.3, J69.3, J70.3
SDA5: J51.51, J53.2, J58.3, J61.2
SDA6: J75.12, J83.3, J93.3, J94.3
SDA7: J75.51, J77.2, J82.3, J85.2
SWDCK: J2.4, J6.21, TP3.P$1
SWDCK1: J7.4, J27.21, TP6.P$1
SWDCK2: J50.4, J51.21, TP9.P$1
SWDCK3: J74.4, J75.21, TP12.P$1
SWDIO: J2.2, J6.23, TP2.P$1
SWDIO1: J7.2, J27.23, TP5.P$1
SWDIO2: J50.2, J51.23, TP8.P$1
SWDIO3: J74.2, J75.23, TP11.P$1
TX1: J6.17, J23.8, J24.8
TX2: J6.22, J25.4, J26.4
TX3: J27.17, J38.8, J47.8
TX4: J27.22, J39.4, J48.4
TX5: J51.17, J62.8, J71.8
TX6: J51.22, J63.4, J72.4
TX7: J75.17, J86.8, J95.8
TX8: J75.22, J87.4, J96.4
USBHOST_N: J4.D-, J6.37, J11.2
USBHOST_N1: J27.37, J28.D-, J42.2
USBHOST_N2: J51.37, J52.D-, J66.2
USBHOST_N3: J75.37, J76.D-, J90.2
USBHOST_P: J4.D+, J6.35, J11.3
USBHOST_P1: J27.35, J28.D+, J42.3
USBHOST_P2: J51.35, J52.D+, J66.3
USBHOST_P3: J75.35, J76.D+, J90.3
USB_N: J1.A7, J1.B7, J6.5
USB_N1: J5.A7, J5.B7, J27.5
USB_N2: J49.A7, J49.B7, J51.5
USB_N3: J73.A7, J73.B7, J75.5
USB_P: J1.A6, J1.B6, J6.3
USB_P1: J5.A6, J5.B6, J27.3
USB_P2: J49.A6, J49.B6, J51.3
USB_P3: J73.A6, J73.B6, J75.3
VIN: BYP.2, C1.1, C2.+, C13.1, F2.2, J6.9, J8.4, J9.1, R4.2, R5.2, R10.2, U5.8
VIN1: BYP1.2, C3.1, C4.1, C8.+, F1.2, J27.9, J40.4, J41.1, R13.2, R14.2, R16.2, U1.8
VIN2: BYP2.2, C12.1, C14.1, C15.+, F3.2, J51.9, J64.4, J65.1, R21.2, R22.2, R24.2, U2.8
VIN3: BYP3.2, C19.1, C20.1, C21.+, F4.2, J75.9, J88.4, J89.1, R29.2, R30.2, R32.2, U3.8
VIN/1: J27.49, R12.2, R13.1
VIN/2: J51.49, R20.2, R21.1
VIN/3: J6.49, R9.2, R10.1
VIN/4: J75.49, R28.2, R29.1
V_USB: BYP.1, D4.A, F2.1, J1.VBUS1, J1.VBUS2
V_USB1: BYP1.1, D12.A, F1.1, J5.VBUS1, J5.VBUS2
V_USB2: BYP2.1, D18.A, F3.1, J49.VBUS1, J49.VBUS2
V_USB3: BYP3.1, D24.A, F4.1, J73.VBUS1, J73.VBUS2

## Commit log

2020-06-01 Many headers added, netted, and placed into form factor
    [MicroMod_ATP_CarrierBoard.brd, MicroMod_ATP_CarrierBoard.sch]
2020-06-02 Trace work for ATP board
    [MicroMod_ATP_CarrierBoard.brd, MicroMod_ATP_CarrierBoard.sch]
2020-06-03 Adds barrel jack for power
    [MicroMod_ATP_CarrierBoard.brd, MicroMod_ATP_CarrierBoard.sch]
2020-07-22 "Reverts" back to a time when barrel jack did not exist
    [MicroMod_ATP_CarrierBoard.brd, MicroMod_ATP_CarrierBoard.sch]
2020-07-22 Shrinks board, adds routing
    * board is now 2 x 3 roughly
    * Added a longer header for MCLK and GND -> went from 10-12 pin
    * Routed SPI, QSPI, and I2S
    [MicroMod_ATP_CarrierBoard.brd, MicroMod_ATP_CarrierBoard.sch]
2020-07-23 Routes the Analog and RX2 traces
    [MicroMod_ATP_CarrierBoard.brd, MicroMod_ATP_CarrierBoard.sch]
2020-07-23 Routes Serial, I2C, and CAN lines
    [MicroMod_ATP_CarrierBoard.brd, MicroMod_ATP_CarrierBoard.sch]
2020-07-23 Reorders the "G#" lines and moves traces so that they hit at 90 degrees
    [MicroMod_ATP_CarrierBoard.brd, MicroMod_ATP_CarrierBoard.sch]
2020-07-23 Moves a few traces - again for 90 degree intersections
    [MicroMod_ATP_CarrierBoard.brd]
2020-07-23 Shifts top header assignements to the left to make space for 3v3 and GND pins
    * Adds top silk to almost all pins
    [MicroMod_ATP_CarrierBoard.brd, MicroMod_ATP_CarrierBoard.sch]
2020-07-24 Adds the rest of the header labels, fixes or approves DRC errors
    * adds Qwiic Mount screw holes
    [MicroMod_ATP_CarrierBoard.brd, MicroMod_ATP_CarrierBoard.sch]
2020-07-24 Renames LED jumpers to their function
    [MicroMod_ATP_CarrierBoard.brd, MicroMod_ATP_CarrierBoard.sch]
2020-07-24 Miters the corners of the board
    [MicroMod_ATP_CarrierBoard.brd]
2020-07-25 Swaps qwiic connectors and their respective headers
    * Moves headers on teh top and bottom so that they can be placed properly
    * Moves the USB host and USB-C connector down so that labels on teh top can fit
    * adjusts the traces accordingly to the part movement
    [MicroMod_ATP_CarrierBoard.brd, MicroMod_ATP_CarrierBoard.sch]
2020-07-25 Moves GND and 3V3 label on top of board along topside of PCB
    [MicroMod_ATP_CarrierBoard.brd, MicroMod_ATP_CarrierBoard.sch]
2020-07-27 Changes silk labels to bi-directional on G# lines, fixes INPUT/OUTPUT labels on
    RTS, CTS, A#, and PWM lines
    [MicroMod_ATP_CarrierBoard.brd, MicroMod_ATP_CarrierBoard.sch]
2020-07-27 Replaces all connectors with their updated version
    [MicroMod_ATP_CarrierBoard.brd, MicroMod_ATP_CarrierBoard.sch]
2020-07-27 Matches length on the QSPI lines
    [MicroMod_ATP_CarrierBoard.brd]
2020-07-27 Swaps one 8 pin header in the test lib to on from the main Sparkfun lib
    [MicroMod_ATP_CarrierBoard.brd, MicroMod_ATP_CarrierBoard.sch]
2020-07-28 Swaps out smaller qwiic labels for larger ones
    [MicroMod_ATP_CarrierBoard.brd, MicroMod_ATP_CarrierBoard.sch]
2020-07-28 Adds testpoint for the RTC lines, adds text for VIN range and warning about using USB host and USB-C at the same time
    [MicroMod_ATP_CarrierBoard.brd, MicroMod_ATP_CarrierBoard.sch]
2020-07-28 Adds a normally open enable jumper to 3.3V EN
    [MicroMod_ATP_CarrierBoard.brd, MicroMod_ATP_CarrierBoard.sch]
2020-07-29 Adds gerber production files.
    [MicroMod_ATP_CarrierBoard-Panel.GBL, MicroMod_ATP_CarrierBoard-Panel.GBO, MicroMod_ATP_CarrierBoard-Panel.GBP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]
2020-07-29 Gives some space in between data lines
    [MicroMod_ATP_CarrierBoard.brd]
2020-07-29 Adds a diode with 220mV Vf to protect back voltage from USB-Host (just in case)
    [MicroMod_ATP_CarrierBoard.brd, MicroMod_ATP_CarrierBoard.sch]
2020-07-29 Changes silk "VUSB" to "VHOST" moves some traces around USB-C to make some space
    [MicroMod_ATP_CarrierBoard.brd]
2020-07-30 Adds a few vias
    [MicroMod_ATP_CarrierBoard.brd]
2020-07-30 Update panel
    [MicroMod_ATP_CarrierBoard-Panel.brd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]
2020-07-30 Changes production board size to 2x2 instead of 1x4
    [MicroMod_ATP_CarrierBoard-Panel.GBL, MicroMod_ATP_CarrierBoard-Panel.GBO, MicroMod_ATP_CarrierBoard-Panel.GBS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]
2020-08-21 Updates SKU on 1x5 connector
    [MicroMod_ATP_CarrierBoard.brd, MicroMod_ATP_CarrierBoard.sch]
2020-08-25 Update M.2 Connector and repanelizes for production
    [MicroMod_ATP_CarrierBoard-Panel.brd, MicroMod_ATP_CarrierBoard.brd, MicroMod_ATP_CarrierBoard.sch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]
2020-09-10 Updates micromod female connector and renames nets
    [MicroMod_ATP_CarrierBoard.brd, MicroMod_ATP_CarrierBoard.sch]
2020-09-10 Updates silk, fixes Qwiic connector wiring
    [MicroMod_ATP_CarrierBoard.brd, MicroMod_ATP_CarrierBoard.sch]
2020-09-10 Updates production files
    [MicroMod_ATP_CarrierBoard-Panel.brd, MicroMod_ATP_CarrierBoard.sch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]
2020-09-11 Revert "Updates production files"
    This reverts commit 213e6b1cbeb41024665e9e154624d95cc9d0b3ef.
    [MicroMod_ATP_CarrierBoard-Panel.brd, MicroMod_ATP_CarrierBoard.sch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]
2020-09-15 Fixes some proportional font, swaps SDA and SCL on I2C qwiic connector, adds additional qwiic logo
    [MicroMod_ATP_CarrierBoard.brd, MicroMod_ATP_CarrierBoard.sch]
2020-09-16 Updates production files with new silk and qwiic connector fixes
    [MicroMod_ATP_CarrierBoard-Panel.brd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]

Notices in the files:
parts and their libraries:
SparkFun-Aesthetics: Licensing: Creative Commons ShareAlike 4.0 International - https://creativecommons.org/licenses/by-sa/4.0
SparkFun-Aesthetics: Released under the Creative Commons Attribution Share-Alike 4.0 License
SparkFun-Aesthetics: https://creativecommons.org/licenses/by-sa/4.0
